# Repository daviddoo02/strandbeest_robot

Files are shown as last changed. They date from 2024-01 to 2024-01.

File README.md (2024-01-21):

# 3D Printed Strandbeest Robot

This project involves an object-following 3D printed Strandbeest robot inspired by Theo Jansen, created as a major project for the MEEN 433 Mechatronics class at Texas A&M.

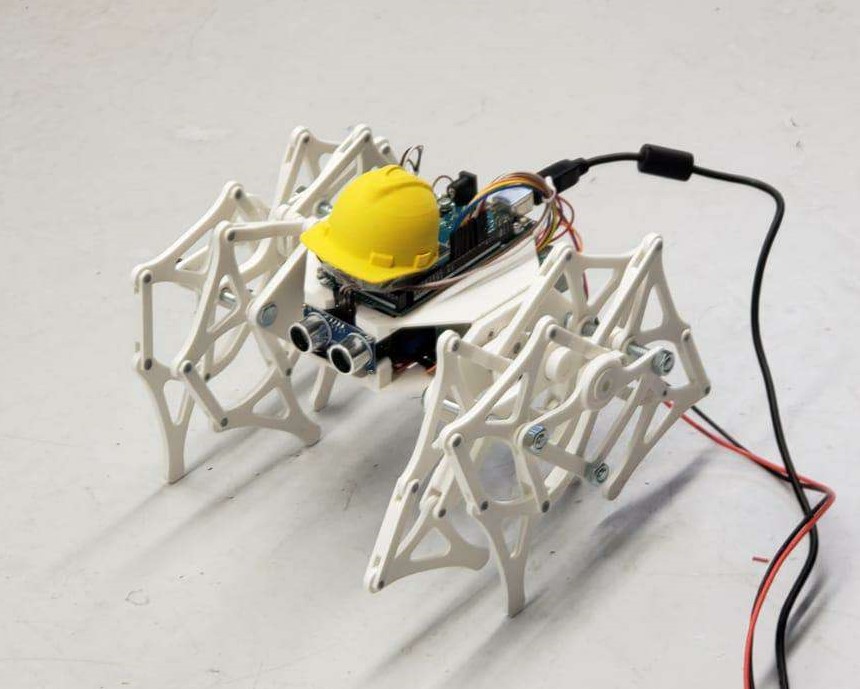
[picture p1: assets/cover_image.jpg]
Cover


## Object Following

The Strandbeest robot is equipped with a sonar sensor, enabling it to follow objects in its vicinity. The implemented feature uses a proportional feedback controller, allowing the robot to dynamically adjust its movements based on the feedback from the sonar sensor.

P.S. The picture on the box is of our TA - we have an inside joke that "it only follows cool people."

Video_demo

### How it Works

1. The robot conducts a scan by alternating the direction of each motor to sweep itself side to side.
2. The sonar sensor detects the distance to nearby objects.
3. The sensor data is passed through a proportional feedback controller to calculate the speed for each motor.
4. The DC motors are adjusted accordingly to enable the robot to follow the detected object.

## Required Materials

Materials and components used are listed and linked below.

1. [Arduino Mega 2560](https://www.amazon.com/dp/B0046AMGW0/)
2. [Ultrasonic Module Distance Sensor](https://www.amazon.com/dp/B07B94C7KT/)
3. [12V 11RPM DC motors x 2](https://www.amazon.com/dp/B07MYVS56N/)
4. [L298N DC motor driver](https://www.amazon.com/dp/B07BK1QL5T/)
5. [3D printing filament x 1 kg](https://www.amazon.com/dp/B089S1HB8K/)
6. [Jumper Wires](https://www.amazon.com/dp/B01EV70C78)
7. [Metric Nuts and Bolts](https://www.amazon.com/Assortment-M2-M3-M4-M5/dp/B0CBMMPPKF)
8. [9V Battery x 2](https://www.amazon.com/dp/B0BJDCBHDK/)
9. [9V Battery Clip](https://www.amazon.com/dp/B081ZRBDVW/)

## Getting Started

1. Clone this repository:

    ```bash
    git clone https://github.com/daviddoo02/strandbeest_robot.git
    ```

2. Modify the CAD files using Solidworks or use the provided STL files in the `STLs` folder to 3D print your own robot.

3. Purchase the required electronics and materials as listed

4. Print and assemble the strandbeest robot

5. Flash the code onto the Arduino using the code included in the `arduino_code` folder.

6. Power the strandbeest and watch it go!

Feel free to experiment with different scenarios and objects for an interactive experience with your robot.

## Assembly Instructions

Assembly instructions are not currently available. However, if there is a significant demand or requests from users, I will consider creating detailed assembly instructions to guide you through the process.

If you have a specific request for assembly instructions, please feel free to open an issue or reach out through the project's communication channels. Your feedback is valuable, and I'll do my best to support your needs.

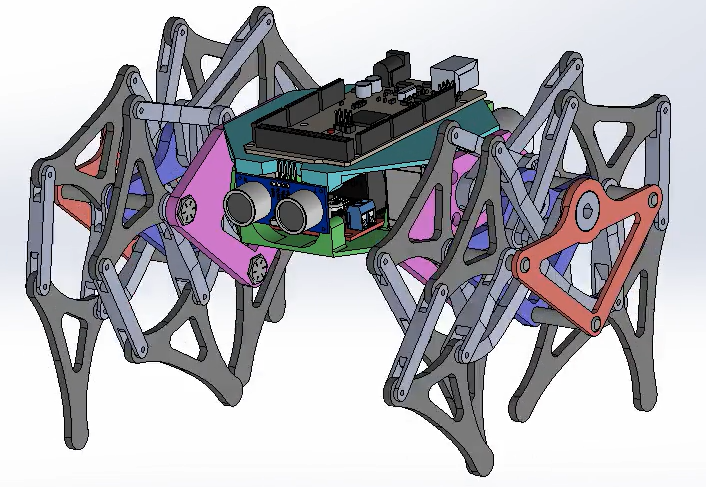
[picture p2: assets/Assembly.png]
Assembly


The schematic is as followed:

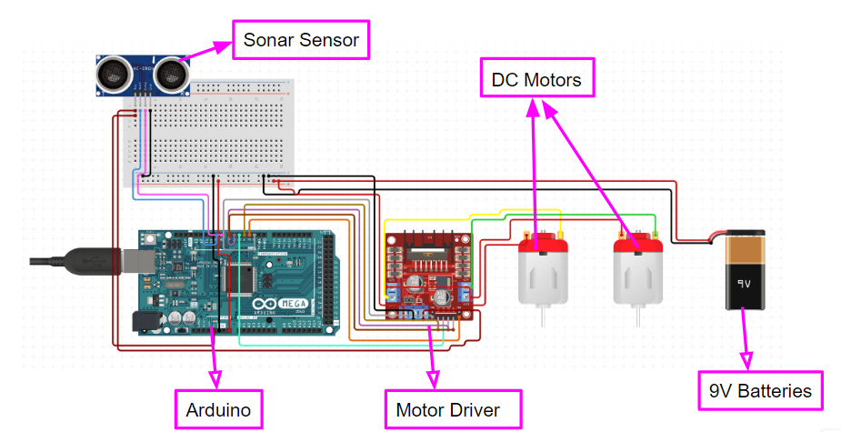
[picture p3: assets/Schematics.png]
Schematics


## License

This project is licensed under the MIT License - see the [LICENSE](LICENSE) file for details.

## Acknowledgments

- Inspired by Theo Jansen's Strandbeest.
- Solidworks was used for the physical design of the robot.
- Construction Helmet STL link [here](https://www.printables.com/model/109726-toddlers-construction-helmet-with-harness/)

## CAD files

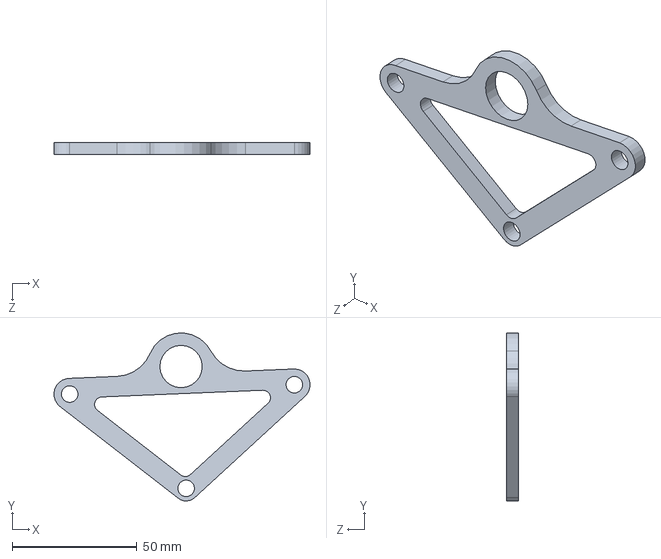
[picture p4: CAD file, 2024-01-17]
CAD/Frame Inner.SLDPRT
102.8 x 67.4 x 5.00 mm

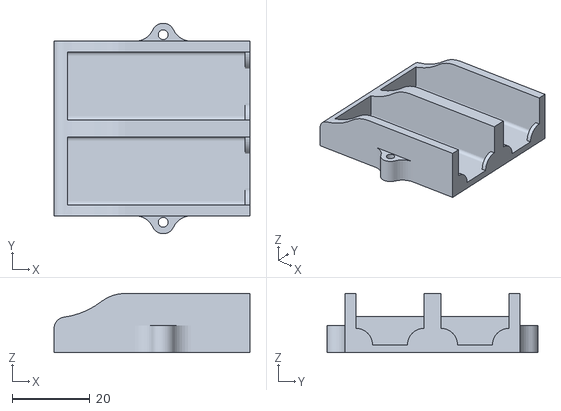
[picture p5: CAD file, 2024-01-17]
STLs/Battery Top.STL
50.5 x 54.2 x 15.2

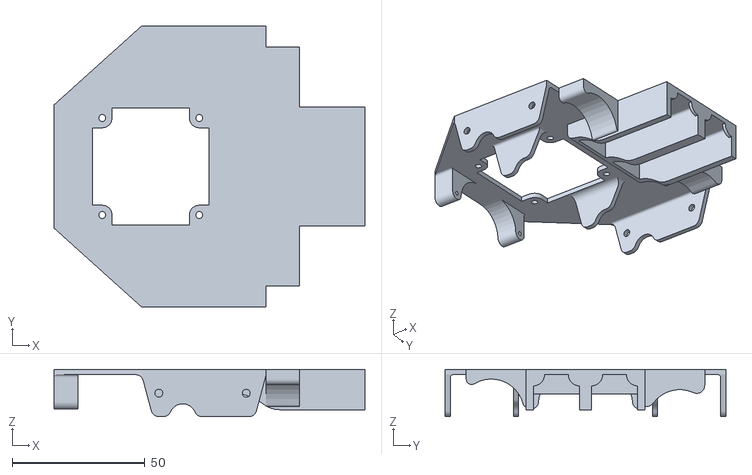
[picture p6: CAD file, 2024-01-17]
STLs/Bottom.STL
117.3 x 106.0 x 17.9

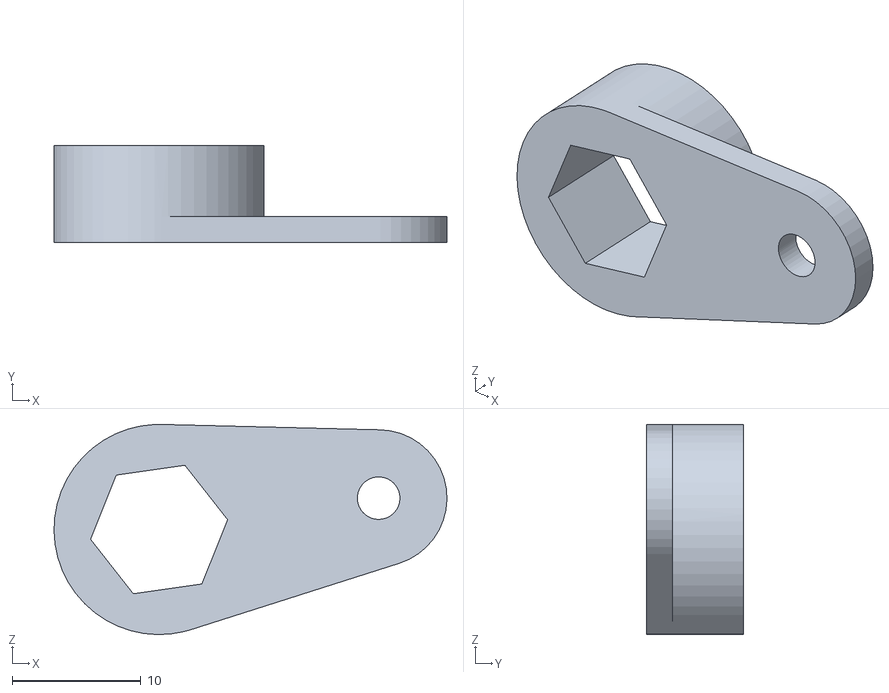
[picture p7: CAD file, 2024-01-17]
STLs/Middle Crank B.STL
30.5 x 7.50 x 16.3

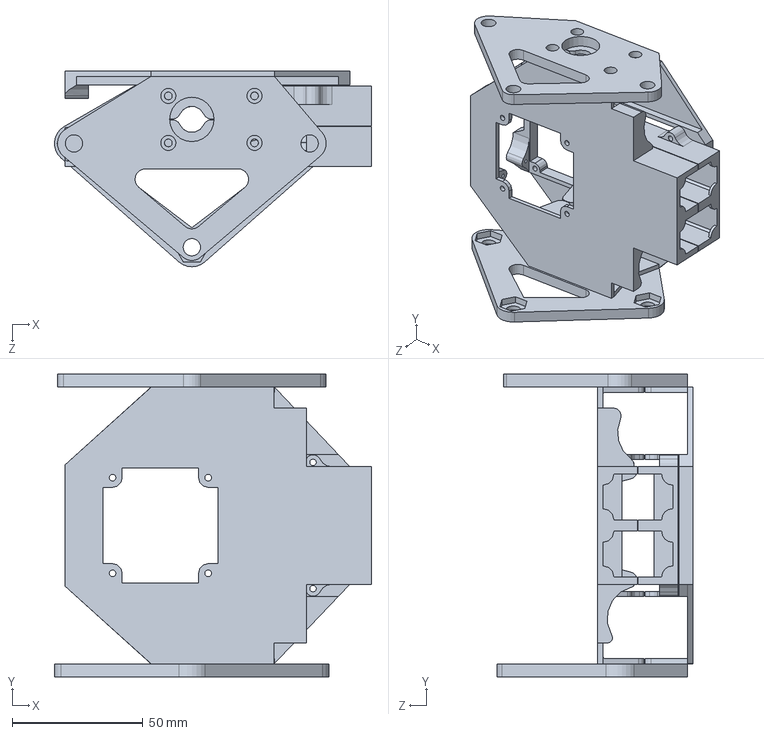
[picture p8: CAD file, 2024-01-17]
CAD/Chassis.SLDPRT
121.4 x 116.0 x 74.9 mm

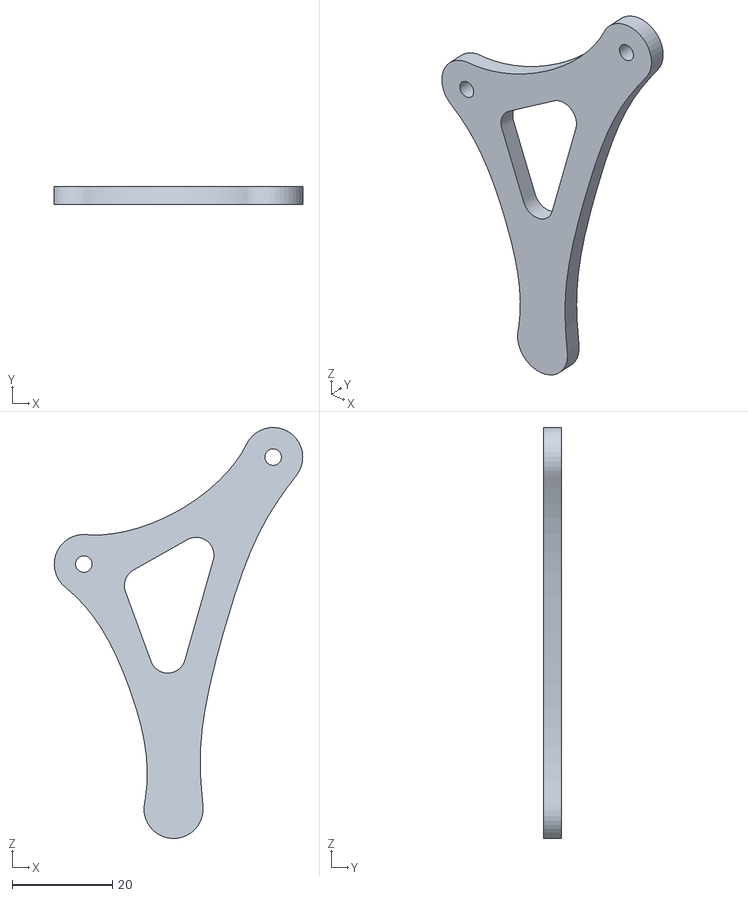
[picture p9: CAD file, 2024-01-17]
STLs/triangle bottom.STL
49.7 x 3.55 x 82.1

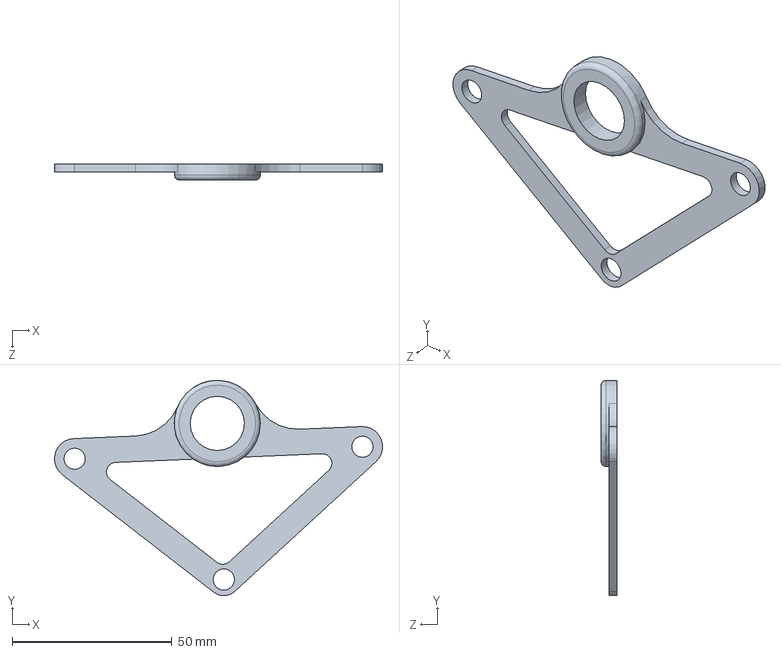
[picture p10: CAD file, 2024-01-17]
CAD/Frame Outer.SLDPRT
102.8 x 67.5 x 5.00 mm

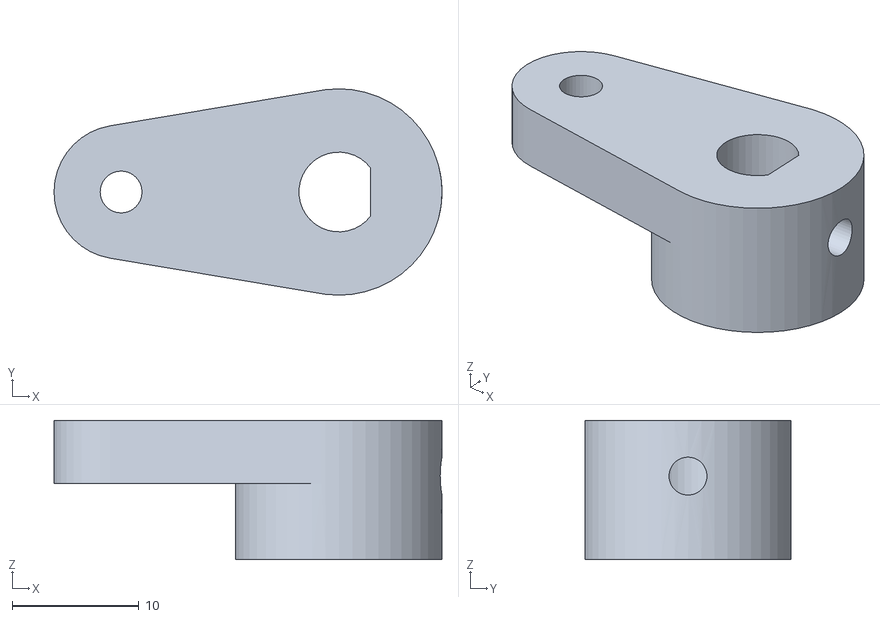
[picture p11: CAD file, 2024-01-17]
STLs/Crank.STL
30.6 x 16.3 x 11.0

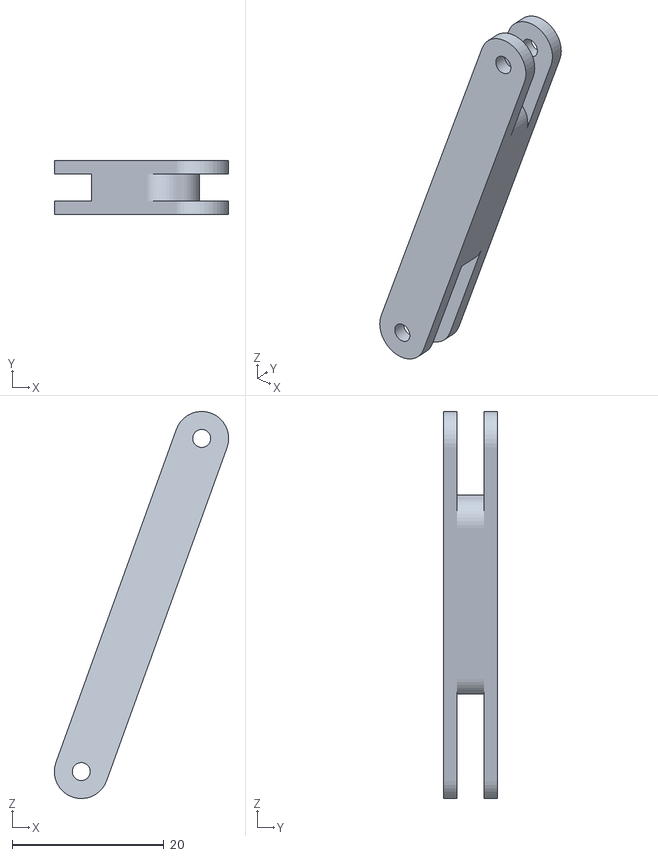
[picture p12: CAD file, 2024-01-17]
STLs/arm f.STL
23.0 x 7.10 x 51.0

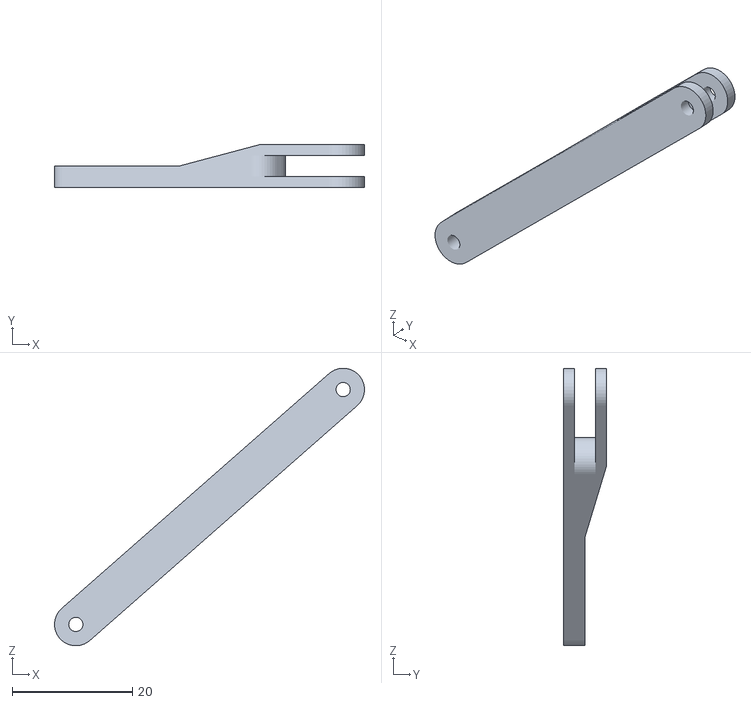
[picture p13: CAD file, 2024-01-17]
STLs/arm j.STL
51.6 x 7.10 x 46.2

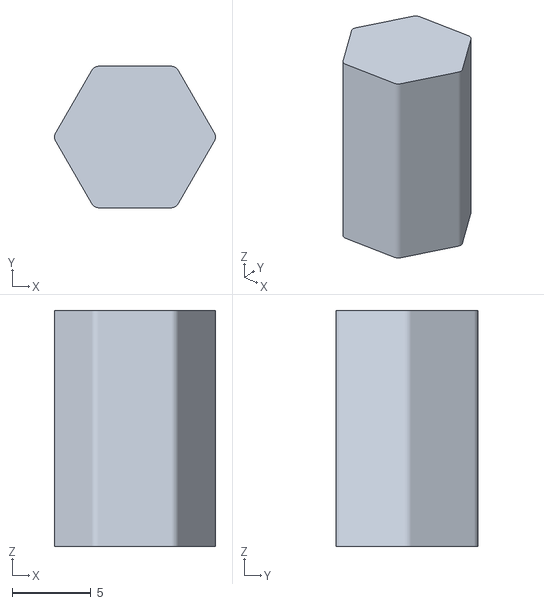
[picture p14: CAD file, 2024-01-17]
STLs/Middle Crank A.STL
10.2 x 9.00 x 15.0

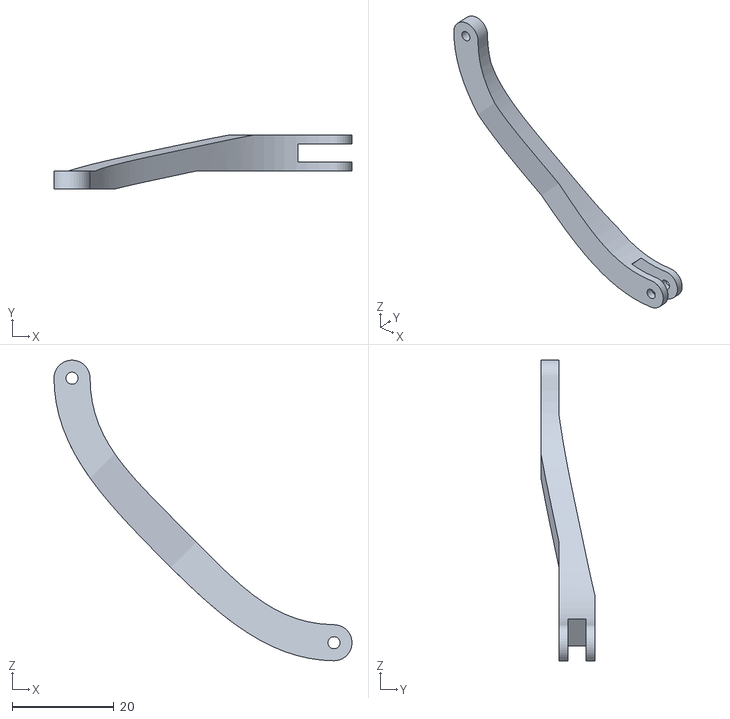
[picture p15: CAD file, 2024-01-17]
STLs/arm k.STL
58.7 x 10.7 x 59.2

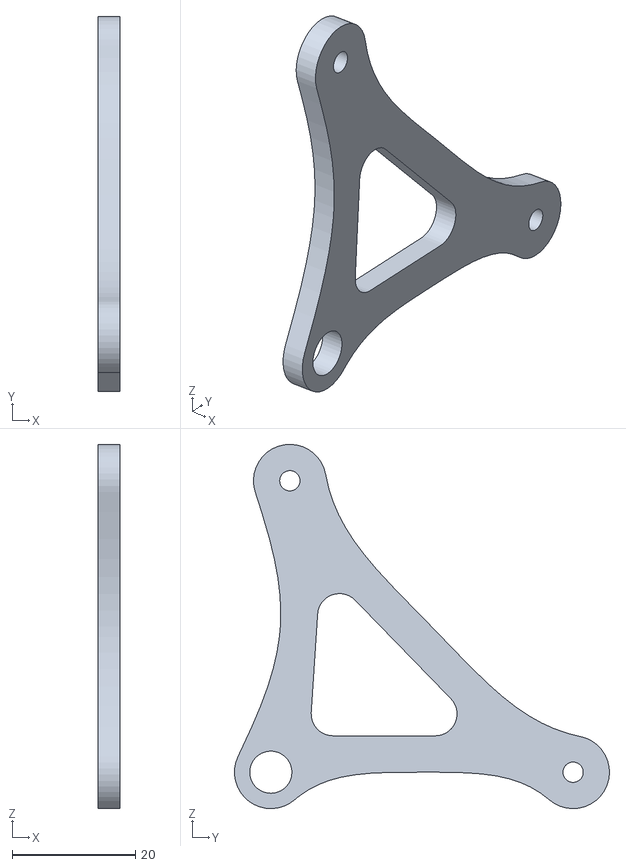
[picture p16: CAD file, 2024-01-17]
STLs/triangle top.STL
3.55 x 61.0 x 59.2

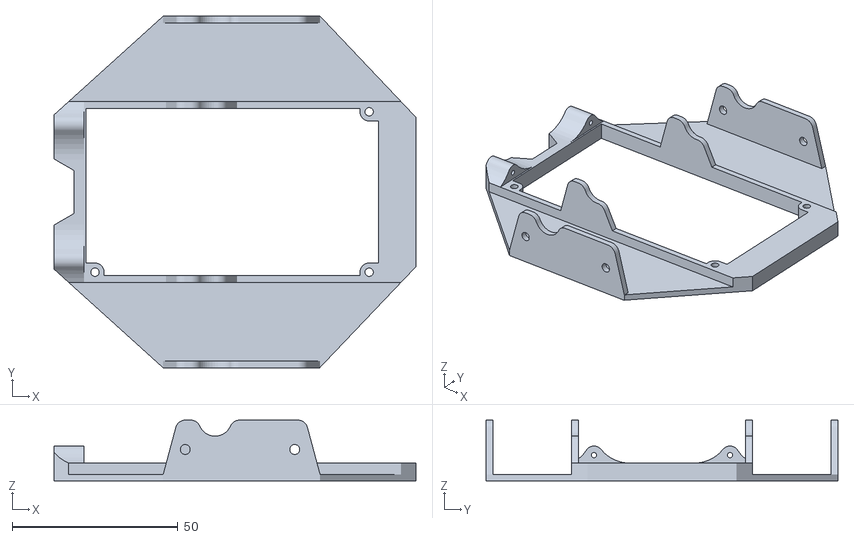
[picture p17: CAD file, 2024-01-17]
STLs/Top.STL
109.1 x 106.0 x 18.3

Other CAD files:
CAD/Middle Crank.SLDASM
CAD/Leg.SLDASM
CAD/Motor Crank.SLDPRT
STLs/Frame.STL
CAD/Hex Screw.SLDPRT
STLs/Chassis.STL
STLs/Frame Outer.STL
STLs/Middle Crank.STL
STLs/Motor Crank.STL
STLs/Side.STL
STLs/arm c.STL

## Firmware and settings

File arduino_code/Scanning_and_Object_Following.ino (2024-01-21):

//  MEEN 433 Final Code

// Defining pins for the two motors
int motor1pin1 = 2;
int motor1pin2 = 3;

int motor2pin1 = 5;
int motor2pin2 = 4;

// Defining pins for the sensor
int trigPin = 7;
int echoPin = 8;

// Defining distance variables
int gap = 20;  // the desired ditance between an object and our robot when it stops
int range = 50; // this is the range within which an object should be placed for our robot to identify it

int n = 0; 
int t = 15; // This is a time value (our robot will spin in one direction for this amount of time)
int rand_val = rand()%2;


void setup() {
  // put your setup code here, to run once:
  Serial.begin(9600);

  // Motor Stuff
  pinMode(motor1pin1, OUTPUT);
  pinMode(motor1pin2, OUTPUT);

  pinMode(motor2pin1, OUTPUT);
  pinMode(motor2pin2, OUTPUT);

  pinMode(9, OUTPUT);
  pinMode(10, OUTPUT);

  // Sonar Sensor Stuff
  pinMode(trigPin,OUTPUT);
  pinMode(echoPin,INPUT);
  
}

void loop() {

  rand_val = rand()%2;

  // Turning on the sonar sensor
  long duration, distance;
  digitalWrite(trigPin, LOW);
  delayMicroseconds(2);
  digitalWrite(trigPin, HIGH);
  delayMicroseconds(10);
  digitalWrite(trigPin, LOW);

  duration = pulseIn(echoPin, HIGH);
  distance = microsecondsToCentimeters(duration);

  //Serial.print(distance);
  //Serial.print("cm");
  //Serial.println();

  //Serial.print("The random value is:");
  //Serial.println(rand_val);

  // Make the robot spin until an object is identified
  
  while(distance > range){
    Serial.println("in the loop");
    n = n+1;
    if(rand_val == 0){
      if(n<t){spin1();}
    else if(n<t*3){spin2();}
    else if(n<t*4){spin1();}
    else if(n>t*4){stopMotors();}
    }
    else{
      if(n<t){spin2();}
      else if(n<t*3){spin1();}
      else if(n<t*4){spin2();}
      else if(n>t*4){stopMotors();}
    }
    
    if(n<4*t){
      Serial.print("n is: ");
      Serial.println(n);
    }
    //spin();
    if(n>4*t){break;}

    digitalWrite(trigPin, LOW);
    delayMicroseconds(2);
    digitalWrite(trigPin, HIGH);
    delayMicroseconds(10);
    digitalWrite(trigPin, LOW); 
    duration = pulseIn(echoPin, HIGH);
    distance = microsecondsToCentimeters(duration);


    //Serial.print("Distance in the loop: ");
    //Serial.println(distance);
    delay(500);
  }
  //Serial.println("out the loop");
  n = 0;
  
  //stopMotors();
  delay(500);

 // if(distance != gap){runMotors(distance-gap);}
  if(abs(distance - gap) > 1){runMotors(distance-gap);}
  else {stopMotors();}

  }


void spin1(){
    Serial.println("Spinning 1");
    analogWrite(9,255);
    analogWrite(10,255);
    digitalWrite(motor1pin1, HIGH);
    digitalWrite(motor1pin2, LOW);

    digitalWrite(motor2pin1, LOW);
    digitalWrite(motor2pin2, HIGH);

}

void spin2(){
    Serial.println("Spinning 2");
    analogWrite(9,255);
    analogWrite(10,255);
    digitalWrite(motor1pin1, LOW);
    digitalWrite(motor1pin2, HIGH);

    digitalWrite(motor2pin1, HIGH);
    digitalWrite(motor2pin2, LOW);
  
}

void runMotors(int direction){
    // Turning on the Motors
    if(direction >0)  // Move the robot forward
    {
      Serial.println("Moving forward");
      analogWrite(9,255);
      analogWrite(10,255);
      digitalWrite(motor1pin1, HIGH);
      digitalWrite(motor1pin2, LOW);

      digitalWrite(motor2pin1, HIGH);
      digitalWrite(motor2pin2, LOW);
      //delay(1000);
    }

    else if(direction < 0)  // Move the robot backward
    {
      Serial.println("Moving backward");
      analogWrite(9,255);
      analogWrite(10,255);
      digitalWrite(motor1pin1, LOW);
      digitalWrite(motor1pin2, HIGH);

      digitalWrite(motor2pin1, LOW);
      digitalWrite(motor2pin2, HIGH);
      //delay(1000);
    }
}

void stopMotors(){
    Serial.println("Motor Stopped");
    digitalWrite(motor1pin1, LOW);
    digitalWrite(motor1pin2, LOW);

    digitalWrite(motor2pin1, LOW);
    digitalWrite(motor2pin2, LOW);
    //delay(1000);

}


long microsecondsToCentimeters(long microseconds) {
  // The speed of sound is 340 m/s or 29 microseconds per centimeter.
  // The ping travels out and back, so to find the distance of the object we
  // take half of the distance travelled.
  return microseconds / 29 / 2;

  exit(0);
}

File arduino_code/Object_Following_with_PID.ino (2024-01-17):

// Define pins for motor control
int motor1Pin1 = 2; // Motor 1 - Forward
int motor1Pin2 = 3; // Motor 1 - Backward

int motor2Pin1 = 5; // Motor 2 - Forward
int motor2Pin2 = 4; // Motor 2 - Backward

// Define pins for the sonar sensor
int trigPin = 7;
int echoPin = 8;
int range = 50; // this is the range within which an object should be placed for our robot to identify it


// Constants for PID control
const int targetDistance = 20; // Target distance in centimeters

// Constants for PID terms
const double Kp = 40; // Proportional gain

void setup() {
  // Initialize motor control pins
  pinMode(motor1Pin1, OUTPUT);
  pinMode(motor1Pin2, OUTPUT);
  pinMode(motor2Pin1, OUTPUT);
  pinMode(motor2Pin2, OUTPUT);

  pinMode(9, OUTPUT);
  pinMode(10, OUTPUT);

  // Sonar Sensor Stuff
  pinMode(trigPin,OUTPUT);
  pinMode(echoPin,INPUT);

  // Initialize serial communication
  Serial.begin(9600);
}

void loop() {
  // Turning on the sonar sensor
  long duration, distance;
  digitalWrite(trigPin, LOW);
  delayMicroseconds(2);
  digitalWrite(trigPin, HIGH);
  delayMicroseconds(10);
  digitalWrite(trigPin, LOW);

  duration = pulseIn(echoPin, HIGH);
  distance = microsecondsToCentimeters(duration);

  // Print values for debugging (optional)
  //Serial.print("Distance: ");
  //Serial.println(distance);

  // Calculate error (difference between target and current distance)
  int error = targetDistance - distance;
  //Serial.println(error);

  // Calculate the control output using proportional control (P-control)
  double output = Kp * error;

  // Map the output to control the motors
  int motorSpeed1 = constrain(output, -255, 255);
  int motorSpeed2 = constrain(output, -255, 255);

  Serial.print("motor speed: ");
  Serial.println(motorSpeed1);

  // Adjust motor speeds based on the error
  if (error < 0) {
    moveForward(motorSpeed1, motorSpeed2); // Move forward if too far from the target
  } else {
    moveBackward(motorSpeed1, motorSpeed2); // Move backward if too close to the target
  }

  delay(100); // Adjust the delay according to your system's requirements
}

void moveForward(int speed1, int speed2) {
  //Serial.println("Moving forward");
  analogWrite(9, abs(speed1));
  analogWrite(10, abs(speed2));
  digitalWrite(motor1Pin1, HIGH);
  digitalWrite(motor1Pin2, LOW);

  digitalWrite(motor2Pin1, HIGH);
  digitalWrite(motor2Pin2, LOW);
  // Adjust motor speeds as needed for forward movement
}

void moveBackward(int speed1, int speed2) {
  //Serial.println("Moving backward");
  analogWrite(9, abs(speed1));
  analogWrite(10, abs(speed2));
  digitalWrite(motor1Pin1, LOW);
  digitalWrite(motor1Pin2, HIGH);

  digitalWrite(motor2Pin1, LOW);
  digitalWrite(motor2Pin2, HIGH);
  // Adjust motor speeds as needed for backward movement
}

long microsecondsToCentimeters(long microseconds) {
  // The speed of sound is 340 m/s or 29 microseconds per centimeter.
  // The ping travels out and back, so to find the distance of the object we
  // take half of the distance travelled.
  return microseconds / 29 / 2;

  exit(0);
}
